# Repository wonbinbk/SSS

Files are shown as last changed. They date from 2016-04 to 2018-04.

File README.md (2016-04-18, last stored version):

SMART SOLDERING PROJECT

1. Introduction
- I want to make a smart soldering station that could do something smart-ish.
- I follow a project on istyle.kr of a Korean hobby. He was using an AVR and
coding in ASM.
- I use PIC microcontroller instead because I am familiar with PIC micro.
Maybe in the future I will port this project into a STM, because STM microcontrollers
are know for its low price.

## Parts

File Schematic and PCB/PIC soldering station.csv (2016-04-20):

Reference | Value | Footprint | Datasheet
U5 | PIC16F876A | Housings_DIP:DIP-28_W7.62mm_LongPads
U1 | LM358 | SMD_Packages:SOIC-8-N
R8 | 10K | Discret:R3
R6 | 1K | Discret:R3
R2 | 10K | Discret:R3
R1 | 1.5K | Discret:R3
C1 | 104 | w_capacitors:cnp_3mm_disc
R4 | 10K | Discret:R3
R3 | 1K | Discret:R3
RV1 | 10K | Buttons_Switches_SMD:SW_SPST_B3S-1100
C3 | 104 | w_capacitors:cnp_3mm_disc
K2 | hakko 907 | w_conn_screw:mors_5p
U4 | TMP101 | TO_SOT_Packages_SMD:SOT-23-6
C20 | 104 | w_capacitors:cnp_3mm_disc
R7 | 4.7K | Discret:R3
R11 | 4.7K | Discret:R3
Q3 | IRLR2908 | SMD_Packages_by_Karl:DPAK-3_GDS
C2 | 104 | w_capacitors:cnp_3mm_disc
C4 | 104 | w_capacitors:cnp_3mm_disc
P1 | 24VAC | Terminal_Blocks:TerminalBlock_Pheonix_MKDS1.5-2pol
D1 | BRIDGE-6A | Terminal_blocks:Diode_bridge_KPBC60xx
R5 | 1.5K | Discret:R3
D2 | 5V_ON | LEDs:LED-3MM
X1 | 32.768kHz | Crystals:Crystal_Round_Horizontal_3mm_BigPad
C11 | 22pF | w_capacitors:cnp_3mm_disc
C13 | 22pF | w_capacitors:cnp_3mm_disc
J1 | DC_INLET | w_conn_misc:dc_socket
X2 | 20Mhz | Crystals:Crystal_HC50-U_Vertical
C15 | 22pF | w_capacitors:cnp_3mm_disc
C16 | 22pF | w_capacitors:cnp_3mm_disc
SW2 | BUTTON1 | Buttons_Switches_ThroughHole:SW_PUSH_SMALL
SW3 | BUTTON2 | Buttons_Switches_ThroughHole:SW_PUSH_SMALL
RV2 | 10K | Buttons_Switches_SMD:SW_SPST_B3S-1100
R23 | 1.5K | Discret:R3
R24 | 1.5K | Discret:R3
R25 | 10K | Discret:R3
R26 | 10K | Discret:R3
D4 | LED1 | LEDs:LED-3MM
D5 | LED2 | LEDs:LED-3MM
R13 | 1.5K | Discret:R3
R14 | 1.5K | Discret:R3
R16 | 1.5K | Discret:R3
R17 | 1.5K | Discret:R3
R18 | 1.5K | Discret:R3
R19 | 1.5K | Discret:R3
R15 | 1.5K | Discret:R3
Q1 | C1815 | TO_SOT_Packages_THT:TO-92_Molded_Wide_Oval
R9 | 560 | Discret:R3
R12 | 22R | Discret:R3
Q2 | A1015 | TO_SOT_Packages_THT:TO-92_Molded_Wide_Oval
R10 | 2.7K | Discret:R3
C8 | 104 | w_capacitors:cnp_3mm_disc
C10 | 104 | w_capacitors:cnp_3mm_disc
C17 | 104 | w_capacitors:cnp_3mm_disc
R22 | 560 | Discret:R3
R21 | 560 | Discret:R3
R27 | 100K | Discret:R3
C19 | 104 | w_capacitors:cnp_3mm_disc
C18 | 104 | w_capacitors:cnp_3mm_disc
D3 | heat_en | LEDs:LED-3MM
U2 | LM7812 | TO_SOT_Packages_THT:TO-220_Neutral123_Vertical_LargePads
U3 | LM7805 | TO_SOT_Packages_THT:TO-220_Neutral123_Vertical_LargePads
C5 | 100uF/ 25V | w_capacitors:CP_6.3x11mm
C7 | 0.1uF | w_capacitors:cnp_3mm_disc
C9 | 0.1uF | w_capacitors:cnp_3mm_disc
C12 | 0.1uF | w_capacitors:cnp_3mm_disc
C6 | 104 | w_capacitors:cnp_3mm_disc
R20 | 1.5K | Discret:R3
AFF1 | CA56-12 | Displays_7-Segment:Cx56-12

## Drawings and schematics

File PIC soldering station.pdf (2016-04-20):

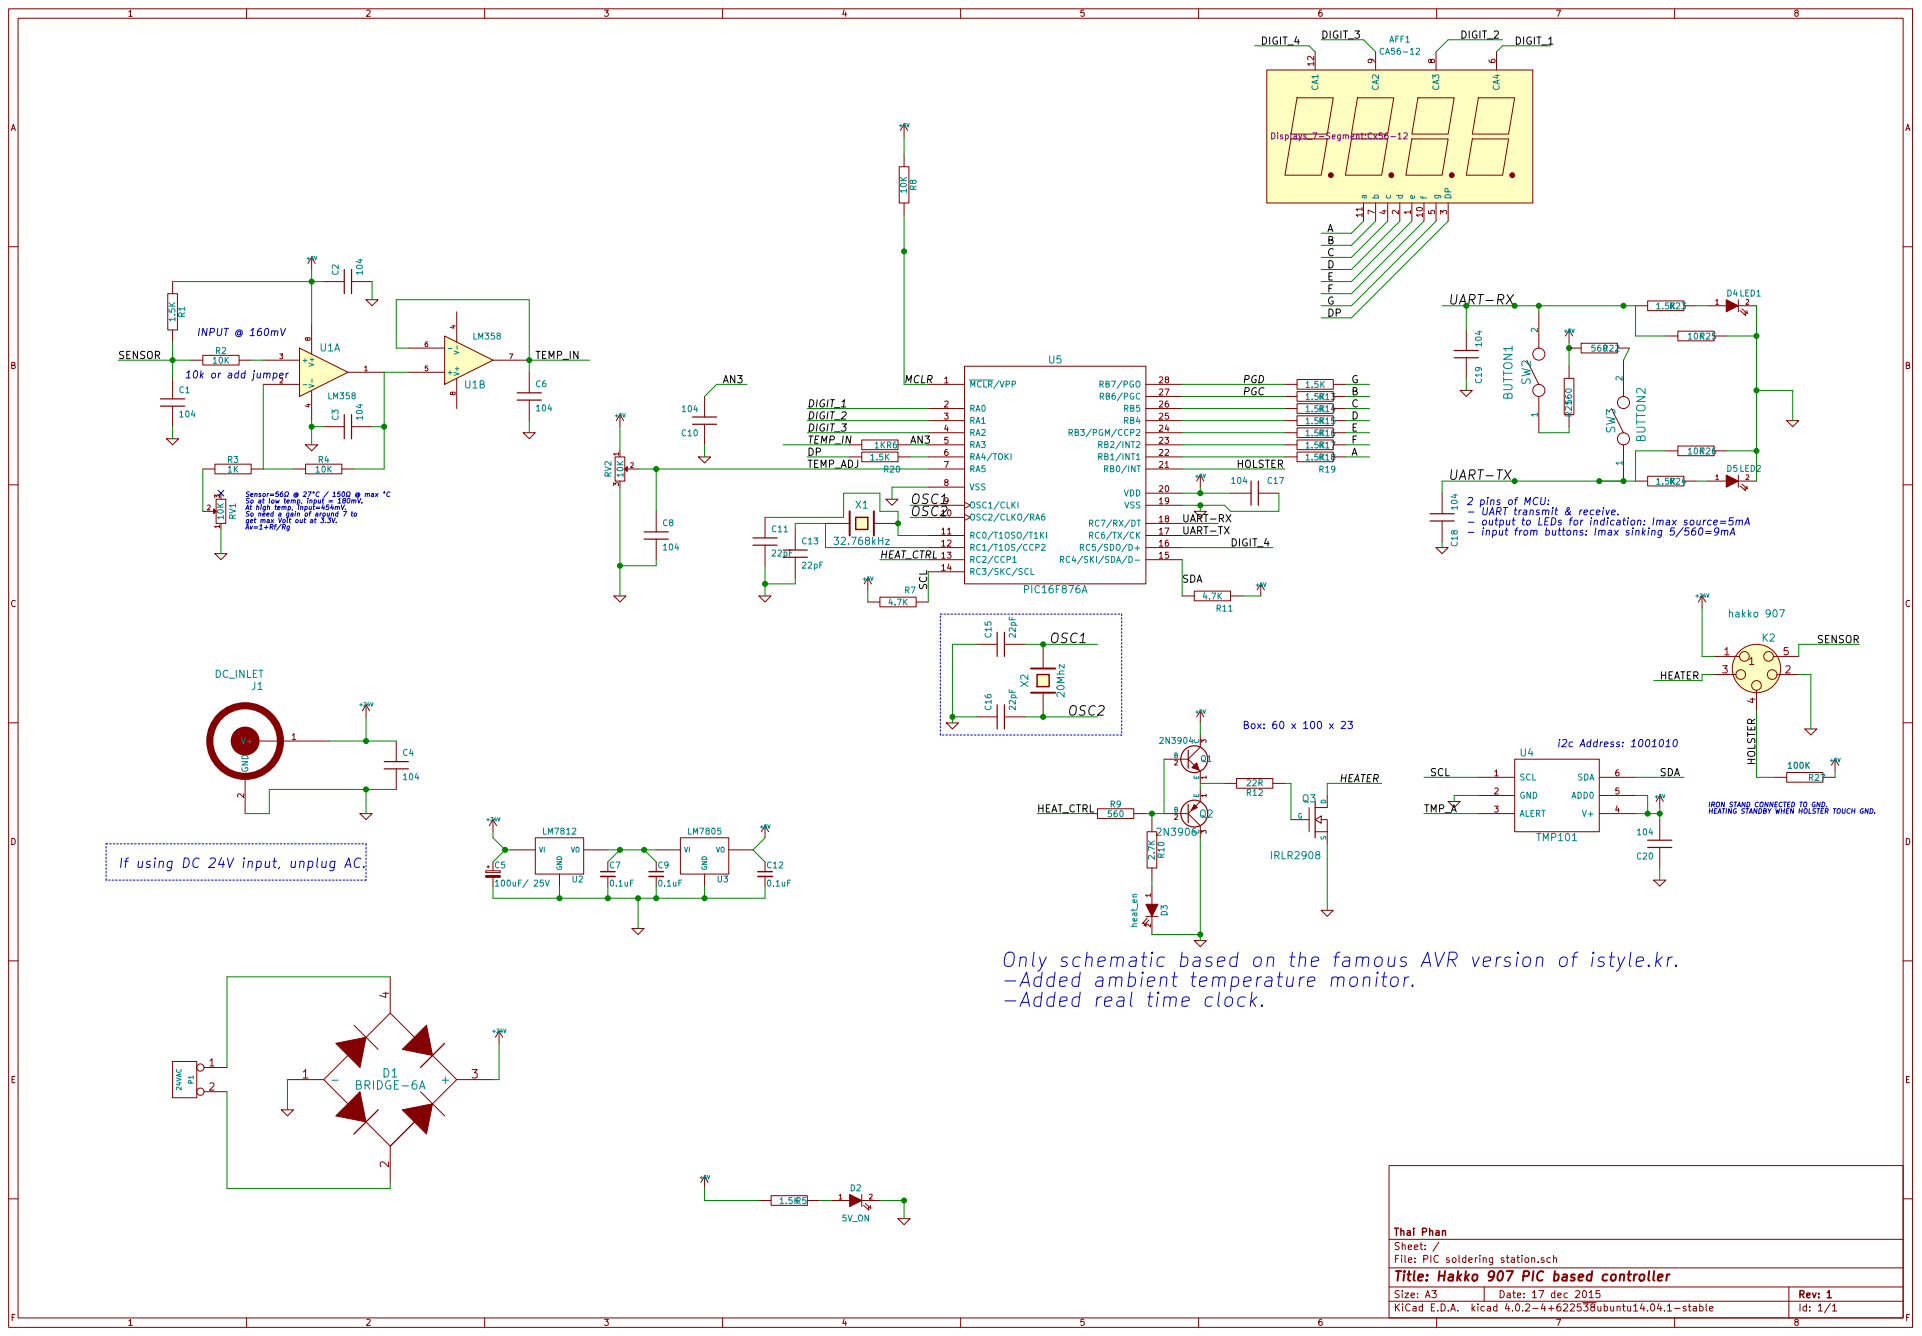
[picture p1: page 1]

IRON STAND CONNECTED TO GND. HEATING STANDBY WHEN HOLSTER TOUCH GND. C19 104 C18 104

2 pins of MCU: - UART transmit & receive. - output to LEDs for indication: Imax source=5mA

- input from buttons: Imax sinking 5/560=9mA

If using DC 24V input, unplug AC.

Only schematic based on the famous AVR version of istyle.kr.
-Added ambient temperature monitor.
-Added real time clock.

File: PIC soldering station.sch Sheet: / Thai Phan

Id: 1/1 Title: Hakko 907 PIC based controller

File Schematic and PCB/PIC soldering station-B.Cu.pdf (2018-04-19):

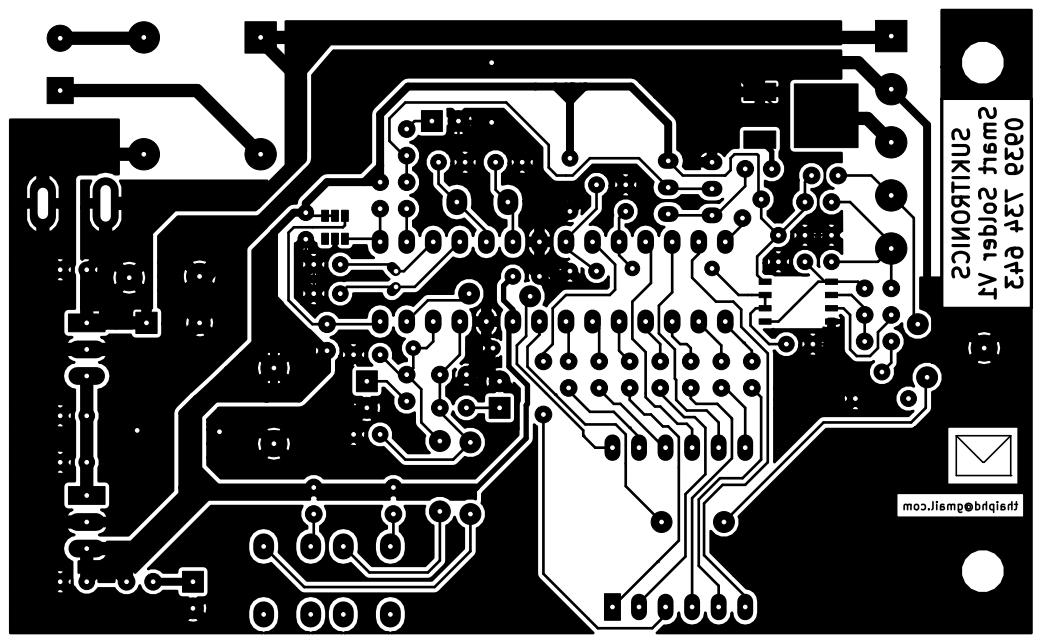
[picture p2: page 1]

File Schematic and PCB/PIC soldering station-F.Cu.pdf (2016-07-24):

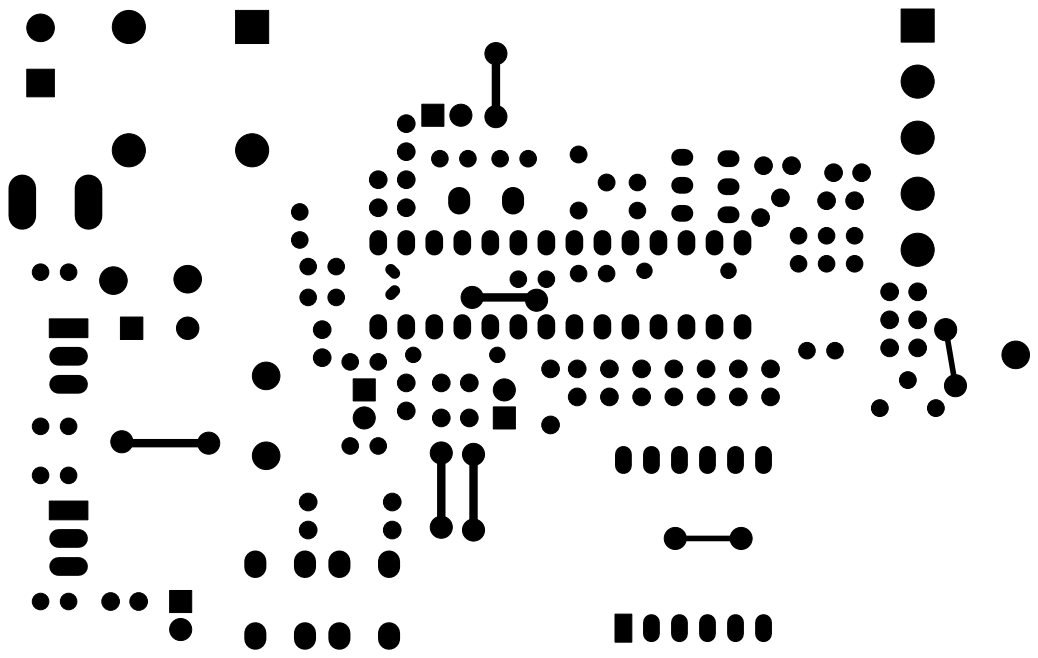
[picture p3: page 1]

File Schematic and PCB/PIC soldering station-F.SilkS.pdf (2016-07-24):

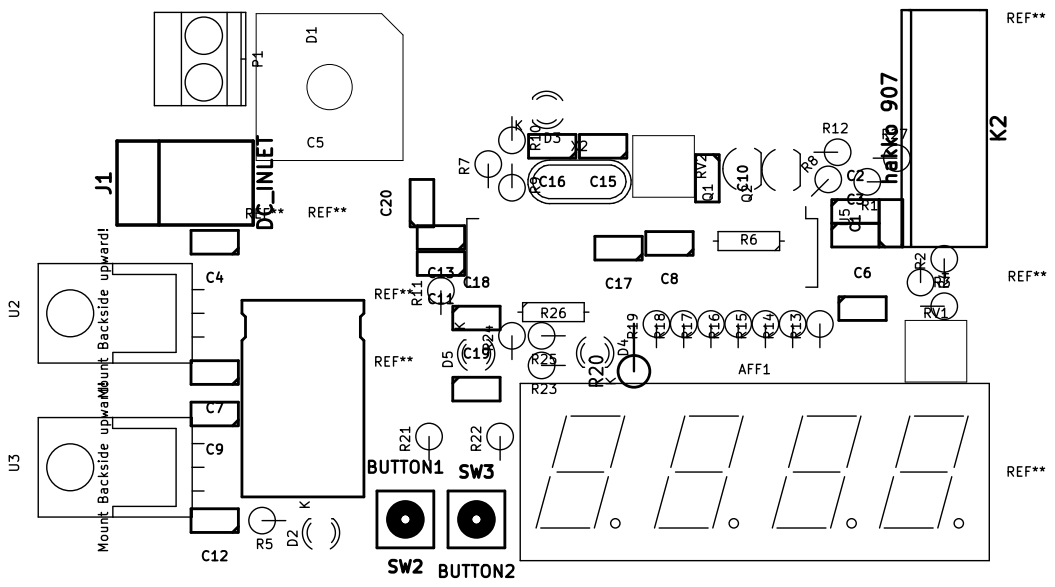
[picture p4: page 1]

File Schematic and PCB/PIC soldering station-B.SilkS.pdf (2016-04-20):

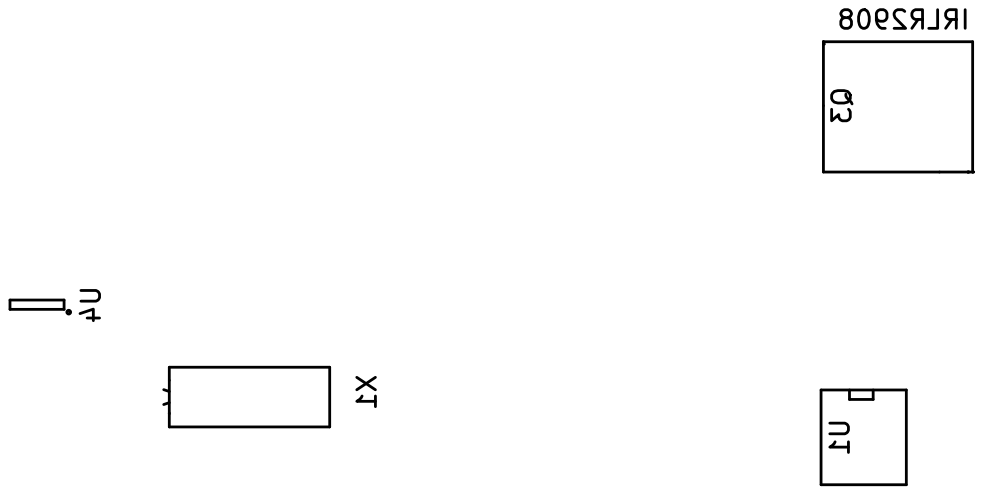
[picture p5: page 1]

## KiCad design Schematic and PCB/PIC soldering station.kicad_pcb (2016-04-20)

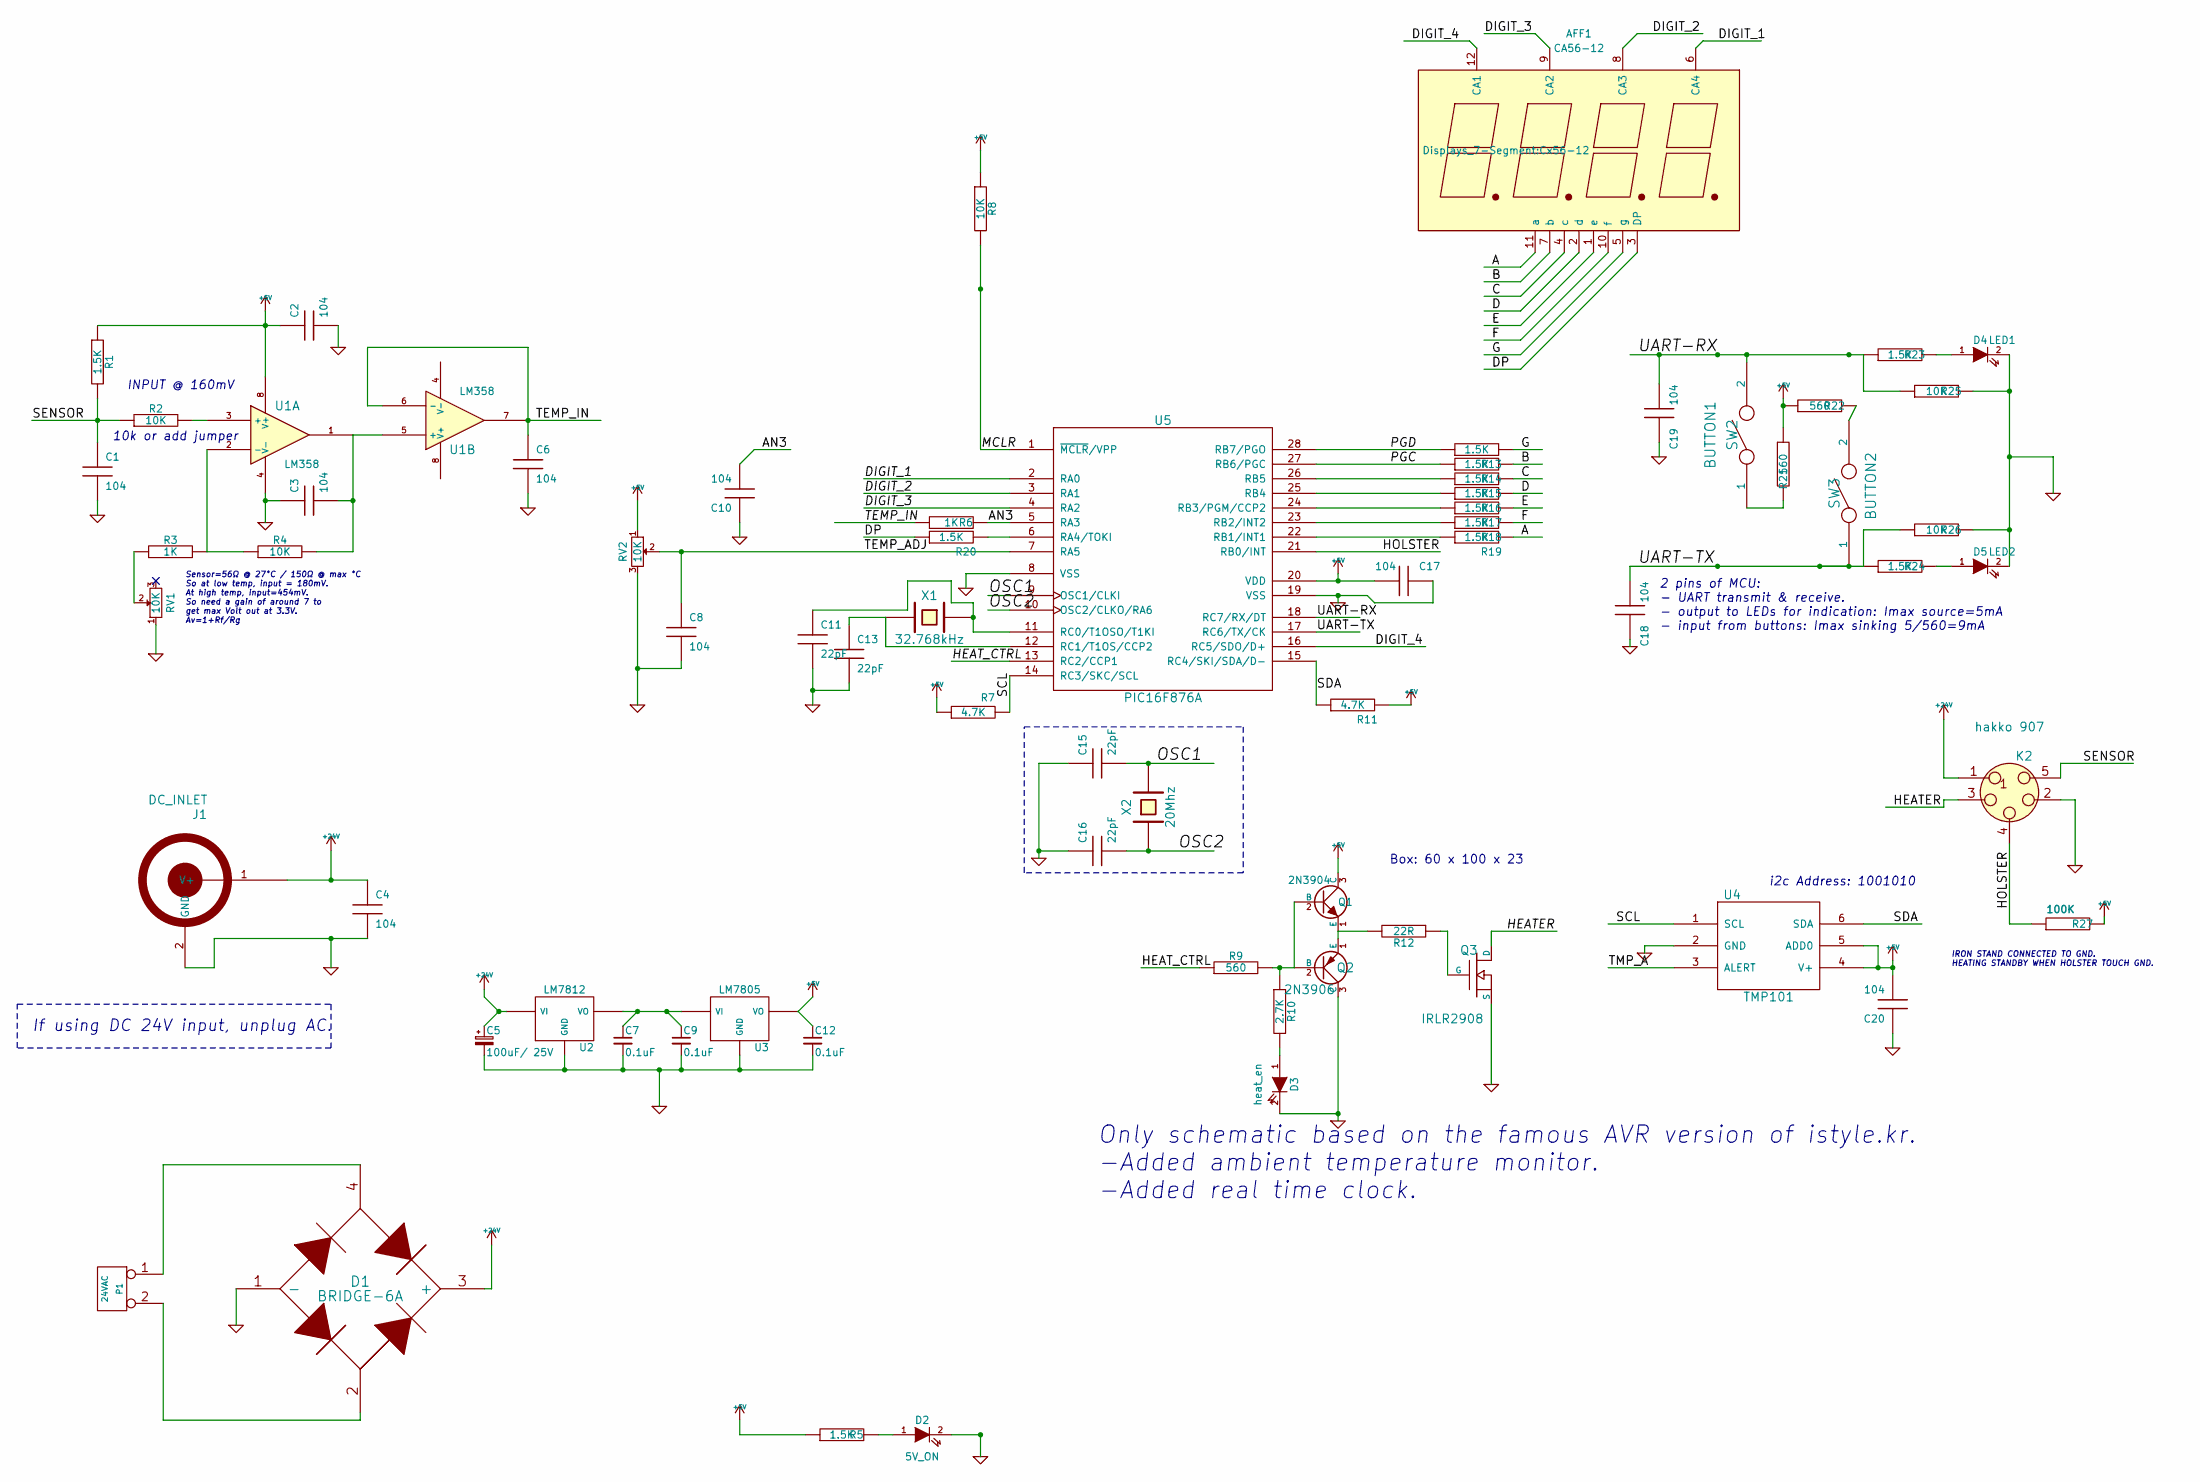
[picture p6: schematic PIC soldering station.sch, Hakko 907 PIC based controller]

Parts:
AFF1: CA56-12; Cx56-12
C1, C2, C3, C4, C6, C8, C10, C17, C18, C19, C20: 104; cnp_3mm_disc
C5: 100uF/ 25V; CP_6.3x11mm
C7, C9, C12: 0.1uF; cnp_3mm_disc
C11, C13, C15, C16: 22pF; cnp_3mm_disc
D1: BRIDGE-6A; Diode_bridge_KPBC60xx
D2: 5V_ON; LED-3MM
D3: heat_en; LED-3MM
D4: LED1; LED-3MM
D5: LED2; LED-3MM
J1: DC_INLET; dc_socket
K2: hakko 907; mors_5p
P1: 24VAC; TerminalBlock_Pheonix_MKDS1.5-2pol
Q1: 2N3904; TO-92_Molded_Wide_Oval
Q2: 2N3906; TO-92_Molded_Wide_Oval
Q3: IRLR2908; DPAK-3_GDS
R1, R5, R13, R14, R15, R16, R17, R18, R19, R20, R23, R24: 1.5K; R3
R2, R4, R8, R25, R26: 10K; R3
R3, R6: 1K; R3
R7, R11: 4.7K; R3
R9, R21, R22: 560; R3
R10: 2.7K; R3
R12: 22R; R3
R27: 100K; R3
RV1, RV2: 10K; SW_SPST_B3S-1100
SW2: BUTTON1; SW_PUSH_SMALL
SW3: BUTTON2; SW_PUSH_SMALL
U1: LM358; SOIC-8-N
U2: LM7812; TO-220_Neutral123_Vertical_LargePads
U3: LM7805; TO-220_Neutral123_Vertical_LargePads
U4: TMP101; SOT-23-6
U5: PIC16F876A; DIP-28_W7.62mm_LongPads
X1: 32.768kHz; Crystal_Round_Horizontal_3mm_BigPad
X2: 20Mhz; Crystal_HC50-U_Vertical

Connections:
+5V: C2.1, C12.1, C17.2, C20.2, Q1.3 (C), R1.1, R5.1, R7.1, R8.1, R11.2, R21.1, R22.1, R27.2, RV2.1, U1.8 (V+), U3.3 (VO), U4.4 (V+), U4.5 (ADD0), U5.20 (VDD)
+24V: C4.1, C5.1, D1.3 (+), J1.1 (V+), K2.1, U2.1 (VI)
/A: AFF1.11 (a), R19.2
/AN3: C10.2, R6.2, U5.5 (RA3)
/B: AFF1.7 (b), R14.2
/C: AFF1.4 (c), R15.2
/D: AFF1.2 (d), R16.2
/DIGIT_1: AFF1.6 (CA4), U5.2 (RA0)
/DIGIT_2: AFF1.8 (CA3), U5.3 (RA1)
/DIGIT_3: AFF1.9 (CA2), U5.4 (RA2)
/DIGIT_4: AFF1.12 (CA1), U5.16 (RC5/SDO/D+)
/DP: AFF1.3 (DP), R20.1
/E: AFF1.1 (e), R17.2
/F: AFF1.10 (f), R18.2
/G: AFF1.5 (g), R13.2
/HEATER: K2.3 (P2), Q3.D
/HEAT_CTRL: R9.1, U5.13 (RC2/CCP1)
/HOLSTER: K2.4 (P3), R27.1, U5.21 (RB0/INT)
/MCLR: R8.2, U5.1 (~MCLR~/VPP)
/OSC1: C15.2, U5.9 (OSC1/CLKI), X2.2
/OSC2: C16.2, U5.10 (OSC2/CLKO/RA6), X2.1
/PGC: R14.1, U5.27 (RB6/PGC)
/PGD: R13.1, U5.28 (RB7/PGO)
/SCL: R7.2, U4.1 (SCL), U5.14 (RC3/SKC/SCL)
/SDA: R11.1, U4.6 (SDA), U5.15 (RC4/SKI/SDA/D-)
/SENSOR: C1.1, K2.5, R1.2, R2.1
/TEMP_ADJ: C8.1, RV2.2, U5.7 (RA5)
/TEMP_IN: C6.1, R6.1, U1.6 (-), U1.7
/TMP_A: U4.3 (ALERT)
/UART-RX: C19.2, R23.1, R25.1, SW2.2, U5.18 (RC7/RX/DT)
/UART-TX: C18.2, R24.1, R26.1, SW3.1, U5.17 (RC6/TX/CK)
GND: C1.2, C2.2, C3.1, C4.2, C5.2, C6.2, C7.2, C8.2, C9.2, C10.1, C11.2, C12.2, C13.2, C15.1, C16.1, C17.1, C18.1, C19.1, C20.1, D1.1 (-), D2.2 (K), D3.2 (K), D4.2 (K), D5.2 (K), J1.2 (GND), K2.2 (P3), Q2.3 (C), Q3.S, R25.2, R26.2, RV1.1, RV2.3, U1.4 (V-), U2.2 (GND), U3.2 (GND), U4.2 (GND), U5.8 (VSS), U5.19 (VSS)
unnamed: C3.2, R4.2, U1.1, U1.5 (+)
unnamed: C7.1, C9.1, U2.3 (VO), U3.1 (VI)
unnamed: C11.1, U5.11 (RC0/T1OSO/T1KI), X1.1
unnamed: C13.1, U5.12 (RC1/T1OS/CCP2), X1.2
unnamed: D1.2, P1.2 (PM)
unnamed: D1.4, P1.1
unnamed: D2.1 (A), R5.2
unnamed: D3.1 (A), R10.2
unnamed: D4.1 (A), R23.2
unnamed: D5.1 (A), R24.2
unnamed: Q1.1 (E), Q2.1 (E), R12.2
unnamed: Q1.2 (B), Q2.2 (B), R9.2, R10.1
unnamed: Q3.G, R12.1
unnamed: R2.2, U1.3 (+)
unnamed: R3.1, RV1.2
unnamed: R3.2, R4.1, U1.2 (-)
unnamed: R15.1, U5.26 (RB5)
unnamed: R16.1, U5.25 (RB4)
unnamed: R17.1, U5.24 (RB3/PGM/CCP2)
unnamed: R18.1, U5.23 (RB2/INT2)
unnamed: R19.1, U5.22 (RB1/INT1)
unnamed: R20.2, U5.6 (RA4/TOKI)
unnamed: R21.2, SW2.1
unnamed: R22.2, SW3.2

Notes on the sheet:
INPUT @ 160mV
Sensor=56Ω @ 27°C / 150Ω @ max °C So at low temp, input = 180mV. At high temp, input=454mV. So need a gain of around 7 to get max Volt out at 3.3V. Av=1+Rf/Rg
10k or add jumper
i2c Address: 1001010
Only schematic based on the famous AVR version of istyle.kr. -Added ambient temperature monitor. -Added real time clock.
If using DC 24V input, unplug AC.
Box: 60 x 100 x 23
2 pins of MCU: - UART transmit & receive. - output to LEDs for indication: Imax source=5mA - input from buttons: Imax sinking 5/560=9mA
IRON STAND CONNECTED TO GND. HEATING STANDBY WHEN HOLSTER TOUCH GND.

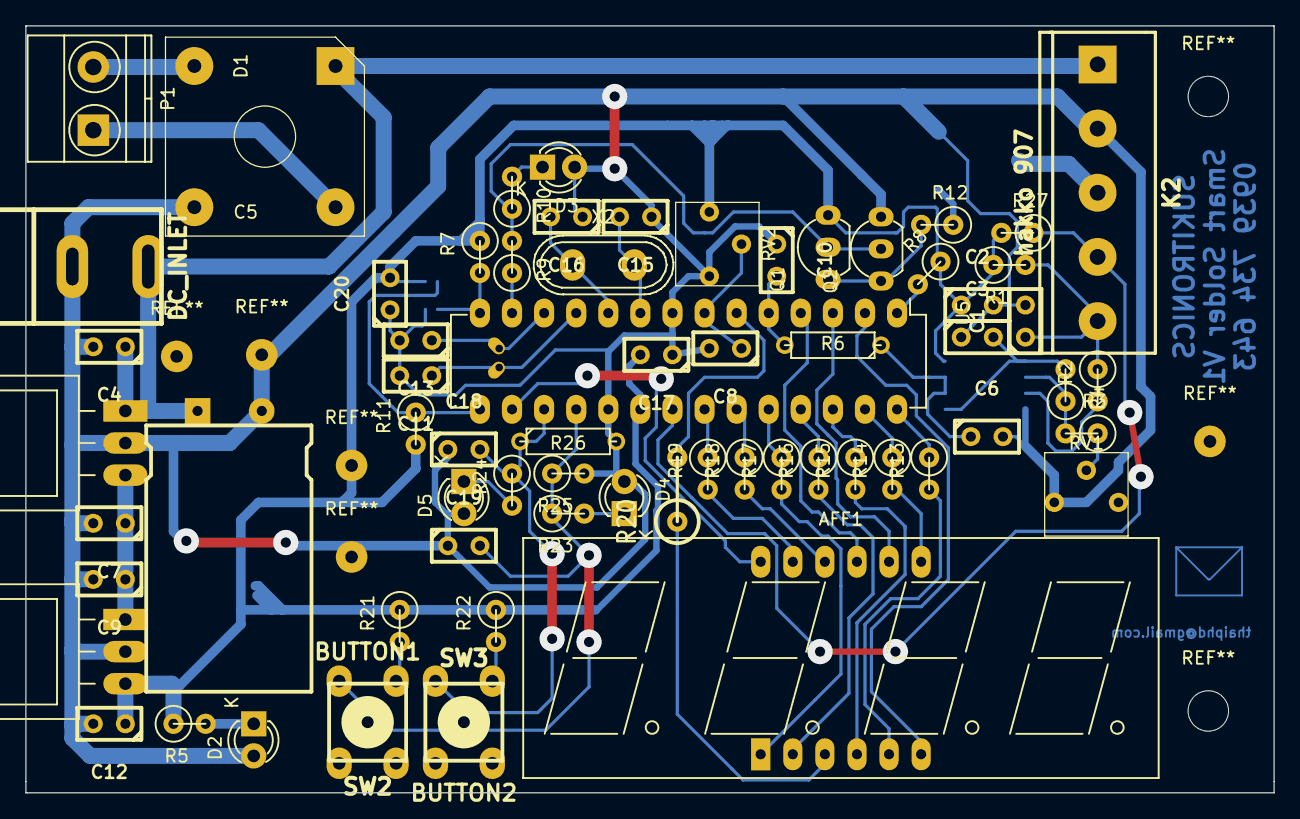
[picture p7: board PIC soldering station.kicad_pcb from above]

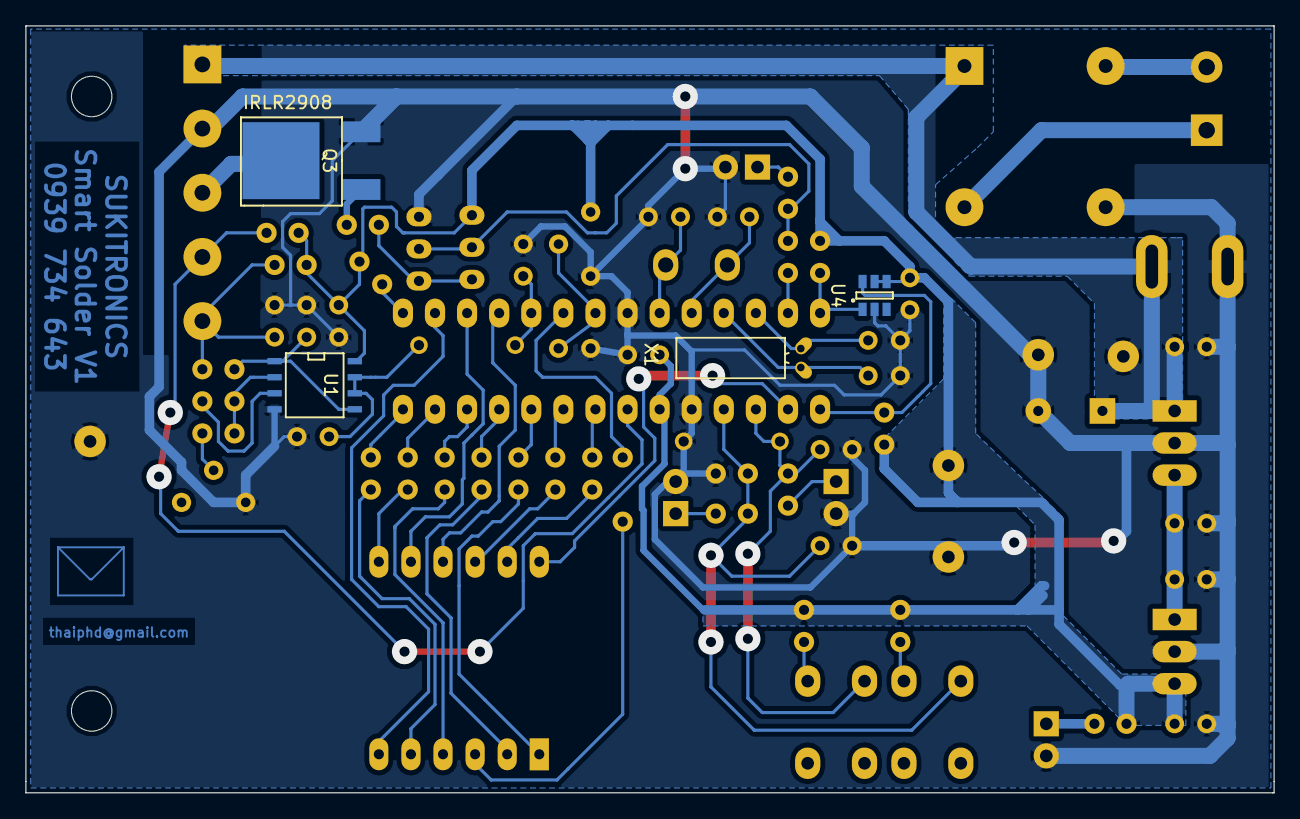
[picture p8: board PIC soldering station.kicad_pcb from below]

Board: 2 copper layers, 98.8 x 60.7 mm, 69 parts (4 on the bottom side), 55 nets.

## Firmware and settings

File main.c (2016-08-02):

/*************************************************************************
**	Author: thaiphd@gmail.com*
**  	Project: SSS - Smart Solding Station, using Hakko 907 iron
**	and PIC16F87XA.
**	Git: www.github.com/wonbinbk
**	Version:3
**	Date: July 19 2016
**	Todo list:
**		-PID control of heater (if necessary(?) Right now it's doing fine
**		without PID)
**		-Allow to adjust PID coefficients while running
**		-Set a timeout when iron rest (display clock) and
**			turn off or set iron to standby mode after 
**			this timeout.
**		-Allow to adjust this timeout while running (in minutes)
*************************************************************************/

#include <xc.h>
#include <stdio.h>
#include <stdlib.h>
#include <conio.h>
#define _XTAL_FREQ 20000000	//for _delay_ms()
#define _BAUD 57600
/*
**	Common Anode 7SEGMENT leds
**	RB7 - G			RA0 - DIGIT 1	
**	RB6 - B			RA1 - DIGIT 2
**	RB5 - C 		RA2 - DIGIT 3
**	RB4 - D			RC5 - DIGIT 4
**	RB3 - E	
**	RB2 - F
**	RB1 - A
**	RA4 - DP
**	RB0 - Interrupt on change for Holster detection
**	
**	The semicolon ":" only display when RA4=0
**	
**		  a
**	    	---
**	       f|g |b
**	    	----
**	       e|  |c
**	    	----		
**	    	 d
*/
#pragma config WDTE=OFF, PWRTE=OFF, CP=OFF, BOREN=ON, DEBUG=OFF
#pragma config LVP=OFF, CPD=OFF, WRT=OFF, FOSC=HS

/* Variable declare */
unsigned int Kp;//, Ki, Kd;
unsigned int tar,pre_tar,T;//,pre_T;
int e;//,pre_e,sum_e;
div_t result;
unsigned char d[4],led[4],l,i;	
unsigned char hour, minute, second;
unsigned char led7[15]=	{
				0b10000000,	//0
				0b10011110,	//1
				0b100100,	//2
				0b1100,		//3
				0b11010,	//4
				0b1001000,	//5
				0b1000000,	//6
				0b10011100,	//7
				0b0,		//8
				0b1000,		//9
				0b1111110,	//-
				0b1100000,	//E
				0b10010,	//H
				0b111000,	//deg
				0b1101110,  //equal
			};
unsigned char display_scan,op_mod,iron_resting, calib_mod, time_out;
__eeprom unsigned char rom_adc0=166, rom_adc100=216;	//t=100*[(ADC-adc0) / (adc100-adc0)] 
unsigned int adc0, adc100;
void init();
void putch(unsigned char c);
void pwm_update(unsigned int duty_cycle);
void print7(unsigned int num, unsigned char display);
unsigned int read_adc(unsigned char channel);
unsigned int read_raw_adc(unsigned char channel);
void heat_control(unsigned int set_T);
void calibration();
#define E 11
#define H 12
#define dash 10
#define S 5
#define deg 13
#define equal 14
#define temp_adj 4
#define temp_in 3
#define tar_unchanged 0
#define tar_changed 1
#define clock 2
#define calib 3
#define four_dash 4	//While calibrating.
#define hr 0
#define mn 1
#define display_error 4
#define time_to_standby 20 	//in minute
#define time_to_turnoff 30	//in minute
#define normal 0
#define standby 1
#define turnoff 2

/*	Interrupt service routine			*/
void __interrupt myisr(void)
	{
		//Check interrupt flag
		if(TMR0IE && TMR0IF)
		{
			TMR0IF=0;
			PORTA=0x10;
			PORTB=led7[d[l]];
			if(l<3)
			{
				PORTA=1<<l | (((!iron_resting) | (second & 0x01))<<4);
				RC5=0;
			}
			else 
			{
				PORTA=0x10;
				RC5=1;
			}	
			l++;
			if (l==4) l=0;	
			if(display_scan!=0) display_scan-=1;
		}
		if(TMR1IE && TMR1IF)
		{
			TMR1IF=0;
			second++;
			if(second==60)
			{
				second=0;
				minute++;
				time_out++;
				if(minute==60)
				{
					minute=0;
					hour++;
					if(hour==24) hour=0;
				}
			}
			TMR1H=0x80;
			TMR1L=0x00;		
		}
	}

void main (void)
	{
		init();
		/****** Check if it reset*/
		print7(8888, calib);
		__delay_ms(500);
		/*************************/
		if(RC6 || RC7) calibration(); //After power on if SW? pressed then go to calibration mode.
		pwm_update(0);
		PORTB=0xFF;
		RC5=0;
		PORTA=0x10;
		Kp=300;
		//Ki=Kd=0;
		adc0= rom_adc0;
		adc100= rom_adc100;
		adc100= adc100 - adc0;
		while(1)
		{	
			tar=read_adc(temp_adj);
			tar=(tar>>3)*5;	//Convert target to Deg C
			if (tar!=pre_tar)	//Only display if changed
			{	
				display_scan=100;	//to display target 100 times. (pause)
				pre_tar=tar;		
			}
			iron_resting=!RB0;//RB0=0 means iron resting on holder
			if(iron_resting)
			{
				print7(hour*100+minute,clock);//and display a clock
				if(time_to_standby<time_out && time_out<time_to_turnoff) op_mod= standby;
				else if(time_out>=time_to_turnoff) op_mod= turnoff;
				else op_mod= normal;
			}
			else
			{
				if(display_scan>0) 	print7(tar,tar_changed);
				else 			print7(T,tar_unchanged);	
				time_out=0;		//Reset time out
				op_mod= normal;
			}
			switch(op_mod)
			{
				case standby:
					if(tar>200)
						heat_control(200);
					else
				case normal:
					heat_control(tar);
					break;
				case turnoff:
					heat_control(0);
					break;
				default:
					break;
			}
			while(RC7 && !RC6 && !RB0)	//Adjust hour
			{
			 	hour++;
			 	if(hour==24) hour=0;
			 	pwm_update(0);
			 	print7(hour*100+minute,clock);
			 	__delay_ms(200);
			}
			while(RC6 && !RC7 && !RB0)	//Adjust minute
			{
				minute++;
				if(minute==60) minute=0;
				pwm_update(0);
				print7(hour*100+minute,clock);
				__delay_ms(200);
			}
		}		
	}	

void heat_control(unsigned int set_T)
{
/***********************************************
** value after calibrating
** for reference, yours iron would be different
** at 0 	degree ADC read 166
** at 100 	degree ADC read 217
***********************************************/
	long duty = 0;
	T=read_adc(temp_in);
	T=(unsigned int)((T-adc0)*(100f/(float)adc100));//Convert T to degree Celsius
	if (set_T>T)	//Since I only use Kp here, if e<=0 don't bother calculating
	{
		e= set_T - T;
		//sum_e= sum_e + e;
		duty = (long)Kp*e ;//+ (long)Ki*sum_e + (long)Kd*(e-pre_e);
		//pre_e= e;
		if (duty>1023) pwm_update(1023);
		else pwm_update((unsigned int)duty);
	}
	else pwm_update(0);
}

/***************************************************************************************************************************
	This function return the hundredth, the tenth and unit of
	required number to display.
	0 <= num <= 999.
	The real LED scanning will happen in ISR (every 6mS).
***************************************************************************************************************************/
void print7(unsigned int num,unsigned char display)
	{
		TMR0IE=0;
		if(abs(tar-num)<display_error) num=tar;
		result=div(num,100);
		d[2]=result.quot;
		num=result.rem;
		result=div(num,10);
		d[1]=result.quot;
		d[0]=result.rem;
		switch (display)
		{
			case tar_unchanged:	//target unchanged, display current temp
				d[3]=d[2];
				d[2]=d[1];
				d[1]=d[0];
				d[0]=deg;
				break;
			case tar_changed:	//target changed, display new target
				d[3]=equal;	
				break;
			case clock:		//in standby mode, display clock
				result=div(d[2],10);
				d[3]=result.quot;
				d[2]=result.rem;
				break;
			case calib:
				result=div(d[2],10);
				d[3]=result.quot;
				d[2]=result.rem;
				break;
			case four_dash:
				d[3]=d[2]=d[1]=d[0]=dash;
				break;
			default:
				break;
		}
		TMR0IE=1;
	}


/***************************************************************************************************************************
	This function update PWM with duty circle.
	PWM frequency is 15.625kHz -> 64uS period.
	Number 64 was chosen for easy calculation.
***************************************************************************************************************************/
void pwm_update(unsigned int duty_cycle)
	{
		CCPR1L= duty_cycle>>2;
		CCP1X = (duty_cycle && 0x02)>>1;
		CCP1Y = duty_cycle && 0x01;
	}

unsigned int read_adc(unsigned char channel)
{
	unsigned int result_adc=0;
	for(i=0; i<8; i++)
	{
		result_adc+=read_raw_adc(channel);
	}
	result_adc= result_adc>>3;
	return result_adc;
}

/***************************************************************************************************************************
	This function queue channel for ADC
	trigger convertion, wait for ISR to return ADC value v.
***************************************************************************************************************************/
unsigned int read_raw_adc(unsigned char channel)
	{
		unsigned int v=0;
		GIE=0;
		ADCON0bits.CHS = channel;
		__delay_us(20);
		GO_DONE=1;
		while(GO_DONE) continue;
		v=(ADRESH<<8) | ADRESL;
		GIE=1;
		return v;
	}
void calibration()
{
	unsigned char calibrating=1;
	while(RC6 || RC7);	//wait for buttons to be released
	while(calibrating)
	{
		print7(0,four_dash);
		__delay_ms(500);
		if(RC6)
		{
			print7(0, tar_unchanged);
			__delay_ms(500);
			adc0= read_adc(temp_in);
			rom_adc0= adc0;
			print7(adc0, calib);
			__delay_ms(1000);
			while(RC6);
		}
		if(RC7)
		{
			print7(100, tar_unchanged);
			__delay_ms(500);
			adc100= read_adc(temp_in);
			rom_adc100= adc100;
			print7(adc100, calib);
			__delay_ms(1000);
			while(RC7);
		}	
	}
}

/**********************INIT PORT AND MODULES*******************************************************************************/	
void init(void)
	{
	//IO
		TRISA = 0x28;	//RA3 & RA5 input RA0,1,2,4 output.
		TRISB = 0x01;	//RB0 input, the rest output.
		TRISC = 0xC3; 	//RC7,6 buttons input, RC5 output, RC4,3 I2C, RC2 output HEAT_CTRL, RC1,0 input for realtime osc.
	//USART for debugging purpose
	/*
		SYNC = 0;		//Synchronous transmit=1, asynch=0
		BRGH = 1;		//for asynch, 1=high speed, 0=low speed
		TX9 = 0;		//9 bit mode = 1, 8 bit mode=0
		SPEN = 1;		//Serial port enable=1, disable=0
		RX9 = 0;		//same as TX9
		CREN = 1;		//Continuous receive=1, disable=0
		FERR = 0;		//Framming error enable=1, disable=0
		OERR = 0;		//Overun error enable=1, disable=0
		SPBRG = _XTAL_FREQ/(16*_BAUD) - 1;		//~36, 0.55% error
		TXEN = 1;		//Transmit enable =1, disable=0
	*/
	//ADC
		ADCON0bits.ADCS = 0b10;	 	//Tad = 64 Tosc= 3.2us
						//Acquisition time =20us, conversion time = 12*Tad=38.4us
						//Total time for ADC ~ 60us
		ADCS2 = 1;
		ADCON0bits.CHS = 3;		//Default AN3
		ADON = 1;
		ADFM = 1;			//Right justified
		ADCON1bits.PCFG = 0;		
			
	//PWM
		CCP1CONbits.CCP1M=0xC;		//PWM mode
		PR2 = 0XFF;			//PWM freq=19.53kHz
						//PWM resolution = 10 bits.
		CCPR1L=0X00;
		CCP1X = 0;
		CCP1Y = 0;			//Duty=0%
		TMR2ON = 1;		
	//Timer0				//Used for scanning LED display
		T0CS = 0;			//Clock source=internal instruction cycle
		PSA=0;			
		OPTION_REGbits.PS=0b110;	//Prescaler 1:128
		TMR0 = 0;			//Interrupt occured every 255*128*0.2=6528us.	
		TMR0IE=1;		
	//Timer1				//Used for RTC
		T1CONbits.T1CKPS = 0;		//Prescaler 1:1
		T1OSCEN = 1;			//Timer1 Osc enabled, to use external oscillator
		TMR1CS = 1;			//Use external clock
		T1SYNC = 1;			//Do not syncronize with internal clock, to use in Sleep mode
		TMR1H=0x80;		
		TMR1ON = 1;			//Enable Timer 1
		TMR1IE = 1;			//Enable Timer 1 interrupt
	//Interrupt
		GIE=1;
		PEIE=1;
		ADIE=0;
		INTEDG=0;
		INTE=0;
	}

/***************************************************************************************************************************
	This function required by printf()
***************************************************************************************************************************/

void putch(unsigned char c)
	{
		while(!TXIF)
			continue;
		TXREG = c;
	}
		
/**************************************************************************************************************************/

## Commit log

2016-04-20 Todo: why the target voltage read wrong?
    [main.c]
2016-04-20 Just add a spreadsheet for easy getting value for 7 segment data port
    [7 Segment LED.ods]
2016-04-20 Working. Fixed adc reading problem: add 30us delay after switching to another channel (to properly charge C_HOLD).
    [main.c]
2016-04-20 Add schematic and PCB
    [PIC soldering station.csv, PIC soldering station.kicad_pcb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]
2016-07-17 Version 1.1: Working OK without PID
2016-07-24 Added auto-standby and auto-poweroff; calibration mode
    [PIC soldering station.sch]
2016-08-02 - Clean up code. Make comments more meaningful... - Add PID tuning data.
    [NoPID.csv, NoPIDwithstepResponse.csv, P100I0D50.csv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]
2018-04-19 Add file via upload
    Fix the plotted via on PIC pin 6.
